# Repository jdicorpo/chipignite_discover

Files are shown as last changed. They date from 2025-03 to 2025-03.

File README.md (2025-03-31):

# Educational FPGA dev board

This FPGA experimentation and development board was developped for [Efabless chipIgnite](https://efabless.com/chipignite) workshops and labs to serve as an easy to use experimentation board and stepping stone towards ASIC digital design, allowing for simple migration of design to [Tiny Tapeout](https://tinytapeout.com) projects.

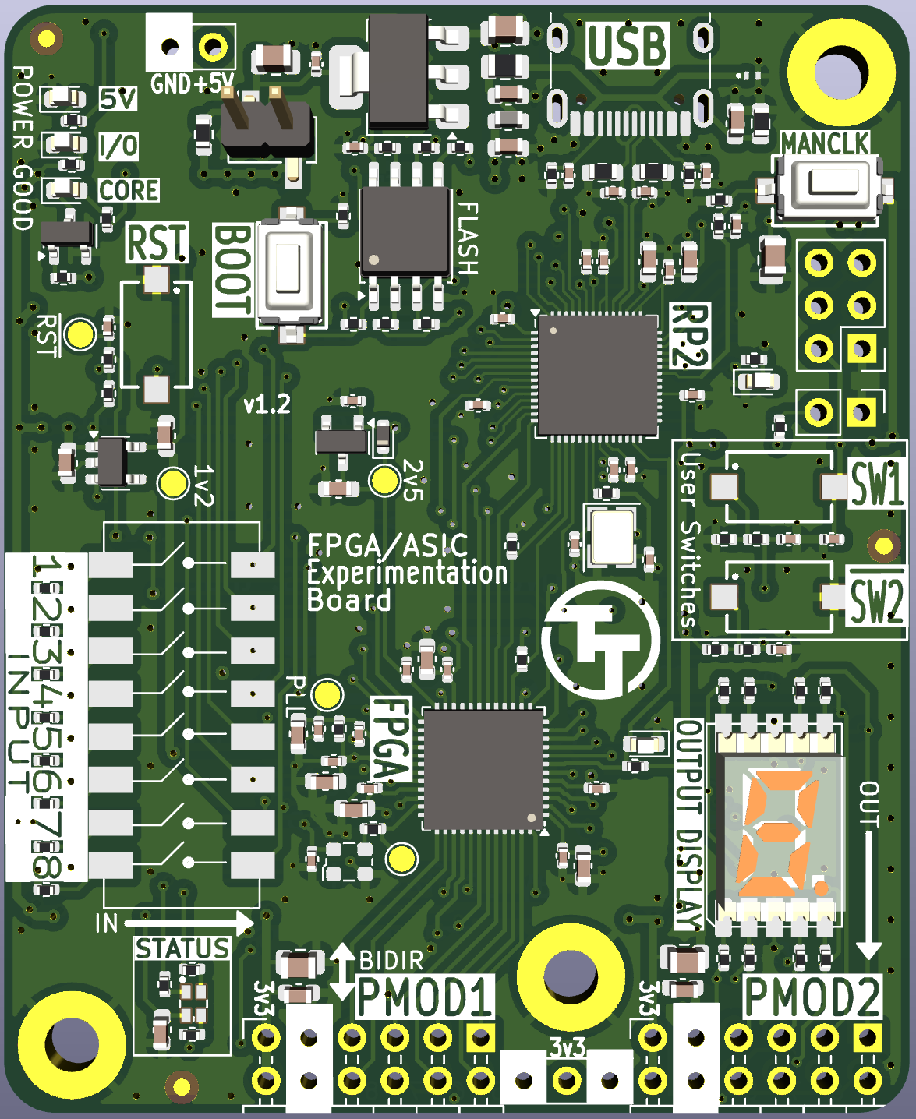
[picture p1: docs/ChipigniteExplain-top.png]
ChipIgnite Explain PCB


It is released as [open hardware](LICENSE), and all the design files are included here, as a[kicad](https://www.kicad.org/) project.

## Schematic

The [full schematic pdf](docs/ChipigniteExplain-schematic.pdf) is available, but is in essence:

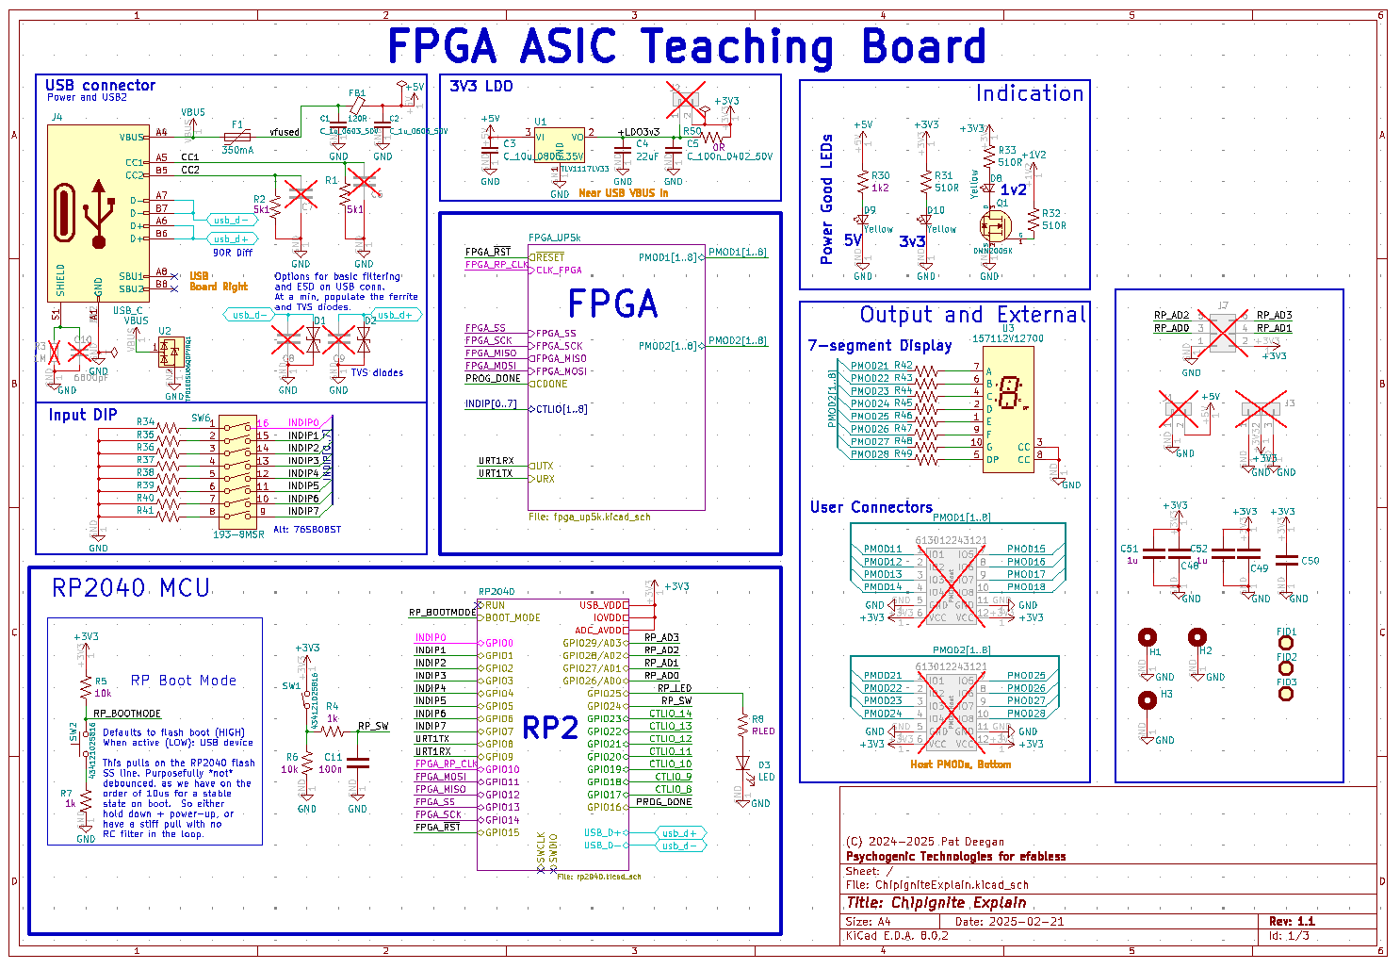
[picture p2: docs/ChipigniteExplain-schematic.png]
Schematic main page


    *  An UP5K FPGA, tied to 8 input switches, 8 outputs through a 7-segment display and 8 additional I/O (the latter two sets also appearing on Pmod headers)
    
    *  An RP2040 MCU, used to manage bitstreams and allow for easy programming of FPGA through drag & drop of UF2 files on a virtual USB drive (powered by [riffpga](https://github.com/psychogenic/riffpga) )

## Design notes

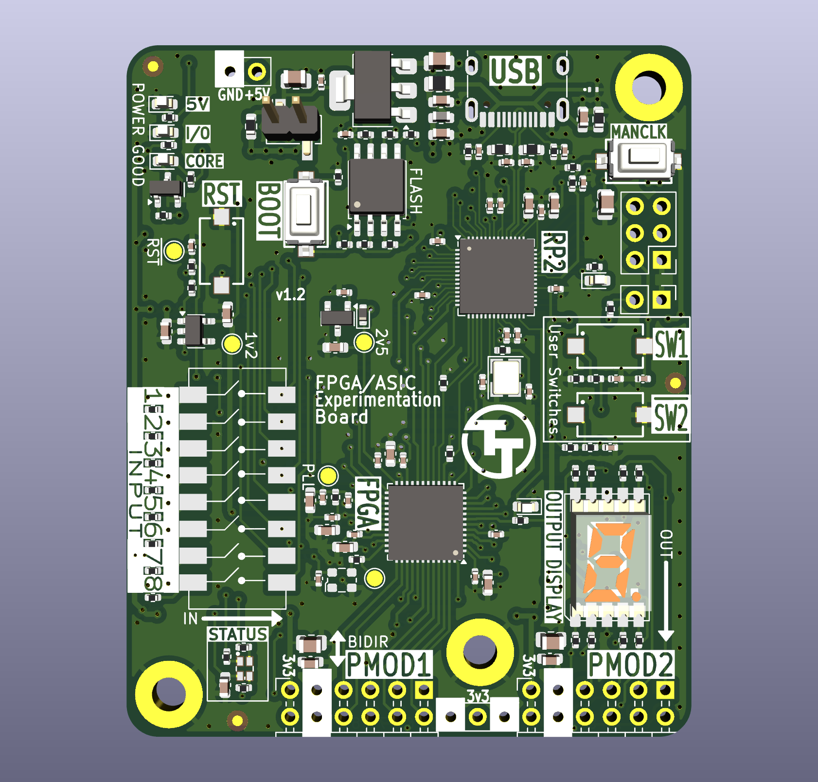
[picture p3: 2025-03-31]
ChipigniteExplain-top.png

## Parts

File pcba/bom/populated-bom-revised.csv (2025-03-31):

Reference | Qty | Value | Characteristics | Footprint | DigikeyPN | Display Value | Display_Value | LCSC | MPN | MPN_ALT | DNP
C1,C2,C51,C52 | 4 | C_1u_0603_50V | 1u 10V XR 0603 | Capacitor_SMD:C_0603_1608Metric | 490-12330-1-ND | 1u | 1u | C5673 | CL10A105KA8NNNC | -- mixed values --
C3,C48,C49,C50 | 4 | C_10u_0805_35V | 10u 10V XR 0805 | Capacitor_SMD:C_0805_2012Metric | 490-10514-1-ND | 10u/35V | 10u/35V | C408142 | GRM21BR6YA106KE43L | LMK212AB7106MG-T
C4 | 1 | 22uF | 22u 6V XR 0805 | Capacitor_SMD:C_0805_2012Metric |  |  |  | C86816 | CL21A226KOQNNNG | GRM21BR61A226ME51K
C5,C11 | 2 | C_100n_0402_50V | 100n 10% 25V XR 0402 | Capacitor_SMD:C_0402_1005Metric | 490-13342-1-ND | 100n | 100n | C100072 | GRM155R71H104KE14J | GRM155R71E104KE14J
C6,C7,C8,C9 | 4 | C_33p_0402_50V | 33pF 0402 | Capacitor_SMD:C_0402_1005Metric | 311-1020-1-ND | 33p/50V | 33p/50V | C107005 | CC0402JRNPO9BN330 |  | DNP
C10 | 1 | 6800pF |  | Capacitor_SMD:C_0603_1608Metric |  |  |  |  |  |  | DNP
D1,D2 | 2 | TVS | Bidir TVS Diode | Resistor_SMD:R_0603_1608Metric | 283-0603ESDA-AEC1CT-ND |  |  | C6961594 | 0603ESDA-AEC1 | C6961594
D3 | 1 | LED | Red LED 0603 | LED_SMD:LED_0603_1608Metric
D8,D9,D10 | 3 | Yellow | Yellow LED, Low 1.8 V Vf | LED_SMD:LED_0603_1608Metric |  |  |  | C72038 | CSL1901YW1 | LY L29K-H1K2-26-Z
F1 | 1 | 350mA | PTC Reset Fuse, 350mA Hold, 0805 | Fuse:Fuse_0805_2012Metric |  |  |  | C1884490 | 0ZCK0035FF2G | SMD0805B035TF
FB1 | 1 | 120R | FERRITE BEAD 120R 0603 | Inductor_SMD:L_0603_1608Metric | 283-MFBM1V1608-121-RCT-ND |  |  | C2649119 | MFBM1V1608-121-R | HFZ 1608PF-151T25
J1 | 1 | Conn_01x02 |  | Connector_PinHeader_2.54mm:PinHeader_1x02_P2.54mm_Vertical |  |  |  |  |  |  | DNP
J2 | 1 | Conn_01x02 |  | Connector_PinHeader_2.54mm:PinHeader_1x02_P2.54mm_Vertical_SMD_Pin1Right |  |  |  |  | 10129380-902001BLF | GEC02SABN-M30 | DNP
J3 | 1 | Conn_01x03 |  | Connector_PinHeader_2.54mm:PinHeader_1x03_P2.54mm_Vertical |  |  |  |  |  |  | DNP
J4 | 1 | USB_C | USB C Right Angle 16P Female USB 2.0 PD | TinyTapeout:USB_C_Receptacle_HRO_TYPE-C-31-M-12 | USB4105-GF-A-120 |  |  | C2927039 | USB-TYPE-C-019 | TYPE-611A-T3
J5,J6 | 2 | 613012243121 |  | TinyTapeout:PinSocket_2x06_P2.54mm_PMODHost1A |  |  |  |  |  |  | DNP
J7 | 1 | Conn_02x03_Odd_Even |  | Connector_PinHeader_2.54mm:PinHeader_2x03_P2.54mm_Vertical |  |  |  |  |  |  | DNP
Q1 | 1 | DMN2005K | N-ch MOSFET Vth < 1.5 | Package_TO_SOT_SMD:SOT-23 | DMN2005K-7DICT-ND |  |  | C2891732 | DMN2005K-7 | SI2302DDS-T1-BE3
R1,R2 | 2 | R_5k1_0402 |  | Resistor_SMD:R_0402_1005Metric | CR0402-FX-5101GLFCT-ND | 5k1 | 5k1 |  | CR0402-FX-5101GLF | RC0402FR-135K1L
R3 | 1 | 1M | 1M 0603 | Resistor_SMD:R_0603_1608Metric |  |  |  | C858907 |  |  | DNP
R4,R7 | 2 | R_1k_0402 | -- mixed values -- | Resistor_SMD:R_0402_1005Metric | CR0402-FX-1001GLFCT-ND | 1k | 1k | C202394 | CR0402-FX-1001GLF | WR04X1001FTL
R5,R6 | 2 | R_10k_0402 | -- mixed values -- | Resistor_SMD:R_0402_1005Metric | 10-ERJ-U02F1002XCT-ND | 10k | 10k | C471764 | RC0402FR-0710KL | WR04X1002FTL
R8 | 1 | RLED |  | Resistor_SMD:R_0402_1005Metric |  | RLED
R30 | 1 | R_1k2_0402 |  | Resistor_SMD:R_0402_1005Metric | 311-1.20KLRCT-ND | 1k2 |  |  | RC0402FR-071K2L
R31,R32,R33,R34,R35,R36,R37,R38,R39,R40,R41 | 11 | 510R |  | Resistor_SMD:R_0402_1005Metric
R42,R43,R44,R45,R46,R47,R48,R49 | 8 | 68R |  | Resistor_SMD:R_0402_1005Metric
R50 | 1 | R_0R_0603_JUMPER |  | Resistor_SMD:R_0603_1608Metric | A106051CT-ND | 0R |  |  | CRG0603ZR
SW1,SW2 | 2 | 434121025816 | -- mixed values -- | TinyTapeout:434121025816 | 2223-TS09-63-25-R-260-SMT-TRCT-ND |  |  | C4364640 or C2689642 or C329185 or C2689642 | 434121025816 | TS09-63-25-R-260-SMT-TR
SW6 | 1 | 193-8MSR | 8 POS SPST DIP PIANO | TinyTapeout:GENERIC_PIANO_8DIP | CT3100CT-ND |  |  | C3293170 | DSPV08LSGET | 2.54-8P TPCB
U1 | 1 | TLV1117LV33 | VREG 3.3V SOT-223-4 | Package_TO_SOT_SMD:SOT-223-3_TabPin2 |  |  |  | C15578 | TLV1117LV33DCYR | AZ1117CH-3.3TRG1
U2 | 1 | TPD1E05U06QDPYRQ1 | TVS DIODE 5.5VWM 14VC 2X1SON | Package_SON:Texas_DPY0002A_0.6x1mm_P0.65mm | 296-47863-1-ND |  |  |  | TPD1E05U06QDPYRQ1 | TPD1E05U06DPYR
U3 | 1 | 157112V12700 | 7 SEGMENT COMMON CATHODE | TinyTapeout:WL_S7DS-157112V12700 | 732-157112V12700DKR-ND |  |  | C6976938 | 157112V12700 | GS3011CR-G

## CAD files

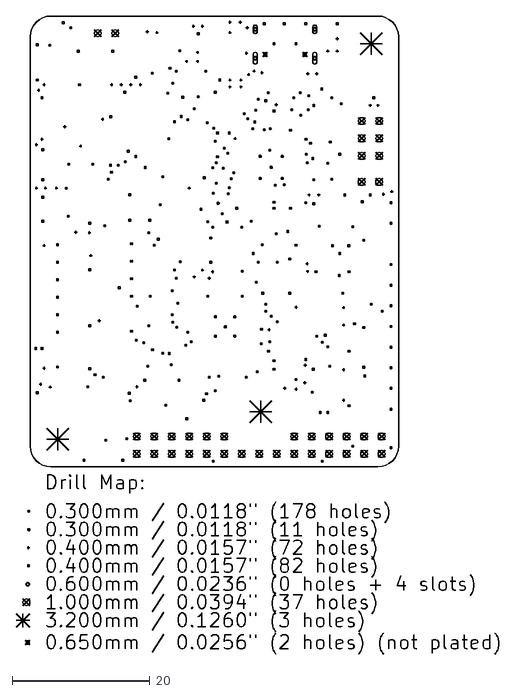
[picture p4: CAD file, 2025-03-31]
pcba/gerber/ChipigniteExplain-drl_map.dxf
70.1 x 92.7

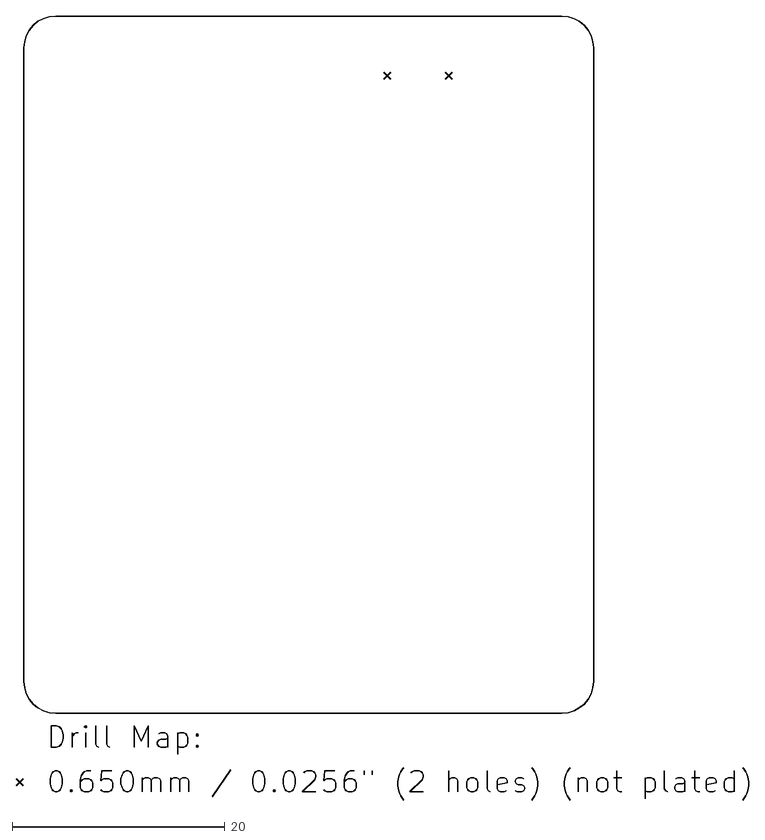
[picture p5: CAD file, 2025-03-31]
pcba/gerber/ChipigniteExplain-NPTH-drl_map.dxf
68.8 x 73.6

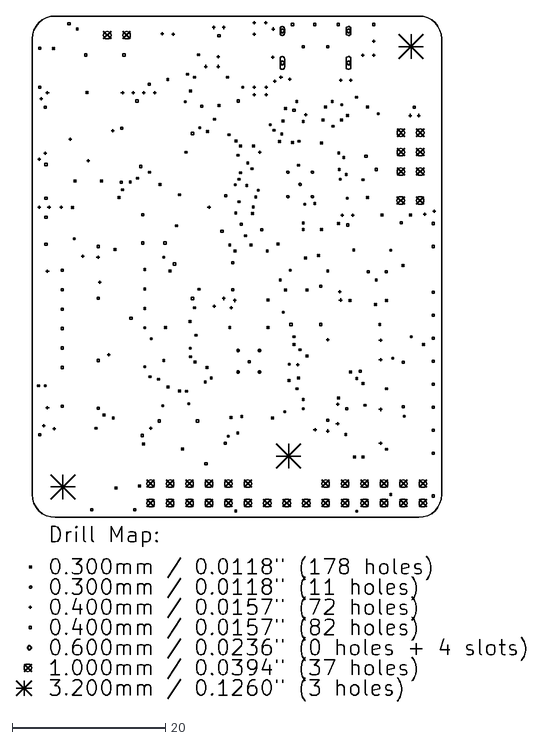
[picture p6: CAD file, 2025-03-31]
pcba/gerber/ChipigniteExplain-PTH-drl_map.dxf
66.5 x 89.5

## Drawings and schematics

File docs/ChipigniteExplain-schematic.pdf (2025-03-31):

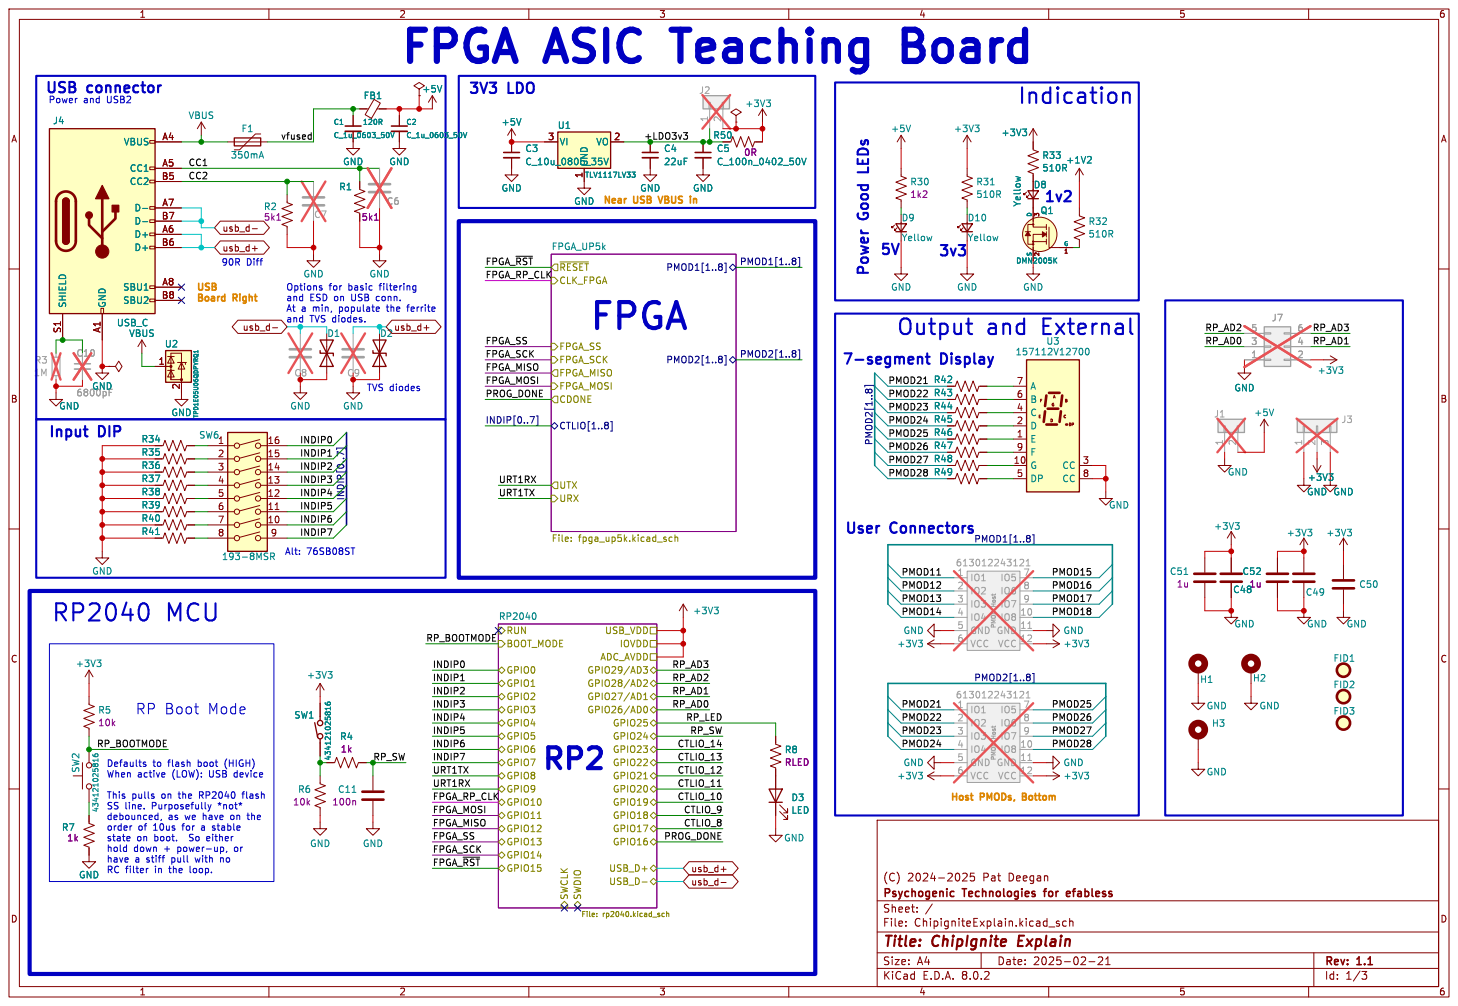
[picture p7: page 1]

FPGA ASIC Teaching Board

1 VO 2 VI 3 GND GND

Options for basic filtering

and TVS diodes. VBUS

order of 10us for a stable

Id: 1/3 Title: ChipIgnite Explain

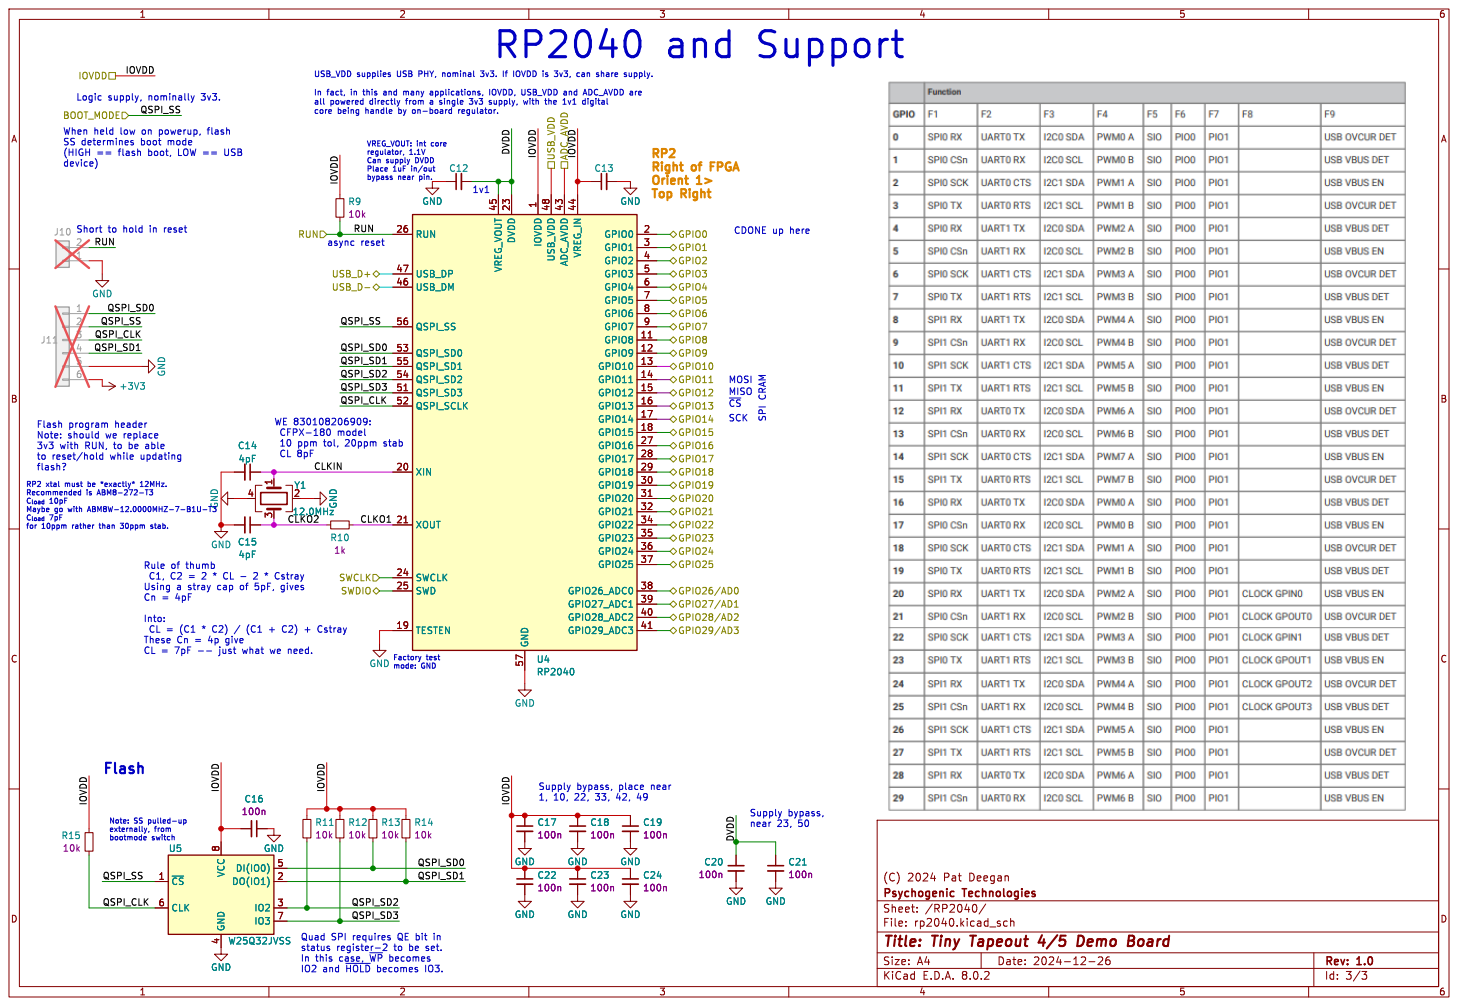
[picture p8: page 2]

(HIGH == flash boot, LOW == USB
device)

VREG_VOUT: int core
Place 1uF in/out bypass near pin.

1 GPIO8 11 GPIO9 12 GPIO10 13 GPIO11 14 GPIO12 15 GPIO13 16 GPIO14 17 GPIO15 18 TESTEN 19 GPIO0 2 XIN 20 XOUT 21 DVDD 23 SWCLK 24 SWD 25 RUN 26 GPIO16 27 GPIO17 28 GPIO18 29 GPIO1 3 GPIO19 30 GPIO20 31 GPIO21 32 GPIO22 34 GPIO23 35 GPIO24 36 GPIO25 37 GPIO26_ADC0 38 GPIO27_ADC1 39 GPIO2 4 GPIO28_ADC2 40 GPIO29_ADC3 41 ADC_AVDD 43 VREG_IN 44 VREG_VOUT 45 USB_DM 46 USB_DP 47 USB_VDD 48 GPIO3 5 QSPI_SD3 51 QSPI_SCLK 52 QSPI_SD0 53 QSPI_SD2 54 QSPI_SD1 55 QSPI_SS 56 GND 57 GPIO4 6 GPIO5 7 GPIO6 8 GPIO7 9 U4 RP2040 C19

1 GPIO8 11 GPIO9 12 GPIO10 13 GPIO11 14 GPIO12 15 GPIO13 16 GPIO14 17 GPIO15 18 TESTEN 19 GPIO0 2 XIN 20 XOUT 21 DVDD 23 SWCLK 24 SWD 25 RUN 26 GPIO16 27 GPIO17 28 GPIO18 29 GPIO1 3 GPIO19 30 GPIO20 31 GPIO21 32 GPIO22 34 GPIO23 35 GPIO24 36 GPIO25 37 GPIO26_ADC0 38 GPIO27_ADC1 39 GPIO2 4 GPIO28_ADC2 40 GPIO29_ADC3 41 ADC_AVDD 43 VREG_IN 44 VREG_VOUT 45 USB_DM 46 USB_DP 47 USB_VDD 48 GPIO3 5 QSPI_SD3 51 QSPI_SCLK 52 QSPI_SD0 53 QSPI_SD2 54 QSPI_SD1 55 QSPI_SS 56 GND 57 GPIO4 6 GPIO5 7 GPIO6 8 GPIO7 9 GND GND

3v3 with RUN, to be able

for 10ppm rather than 30ppm stab. Rule of thumb C1, C2 = 2 * CL - 2 * Cstray

Using a stray cap of 5pF, gives Cn = 4pF

Factory test mode: GND

Note: SS pulled-up

Quad SPI requires QE bit in
In this case, ~{WP}becomes

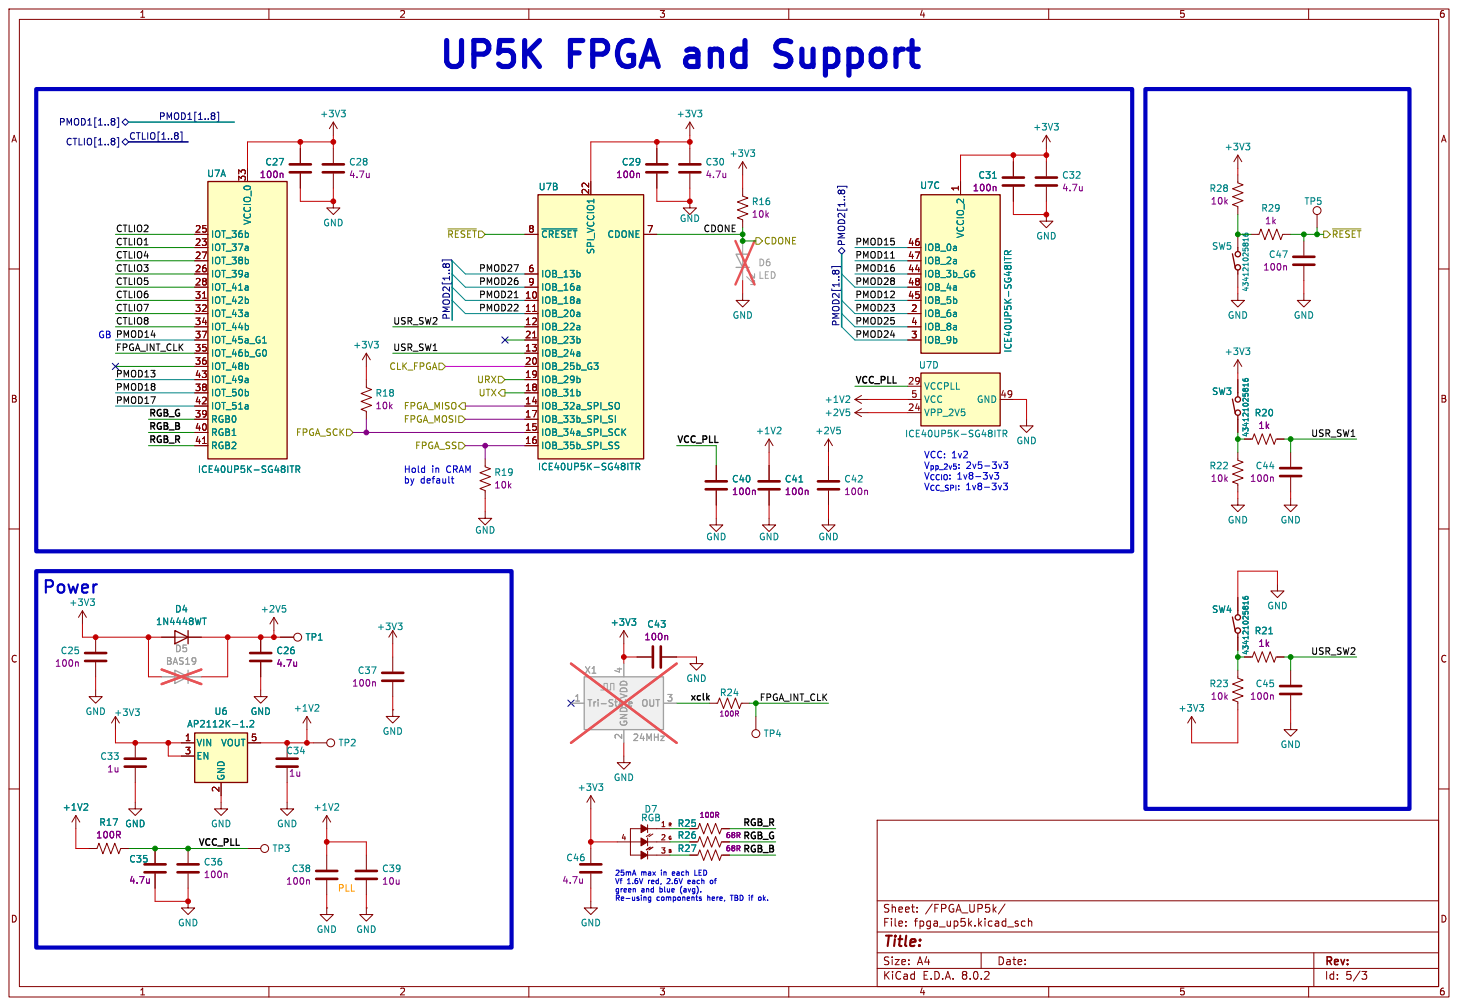
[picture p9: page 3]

25mA max in each LED

Id: 5/3 Title: File: fpga_up5k.kicad_sch Sheet: /FPGA_UP5k/
